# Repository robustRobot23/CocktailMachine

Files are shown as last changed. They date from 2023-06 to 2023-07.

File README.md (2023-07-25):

# CocktailMachine
Check the project Wiki for more information
Currently working on a cocktail machine to pour a shot of liquor, and pump in up to 4 mixers.
Machine contains:
  - 1 Stepper motor
  - 1 A4998 Stepper driver
  - 4 12V DC diagrpham pumps
  - 1 24 LED Neopixel ring
  - 1 Loadcell and HX711 breakout board
  - PCB V1
  - 1 OLED Screen
  - 2 rotary encoder dials and pushbuttons
  
**Code still not fully to working.** 
Currently creating the code structure:
  Machine class
  Cocktail class
  Pump Class

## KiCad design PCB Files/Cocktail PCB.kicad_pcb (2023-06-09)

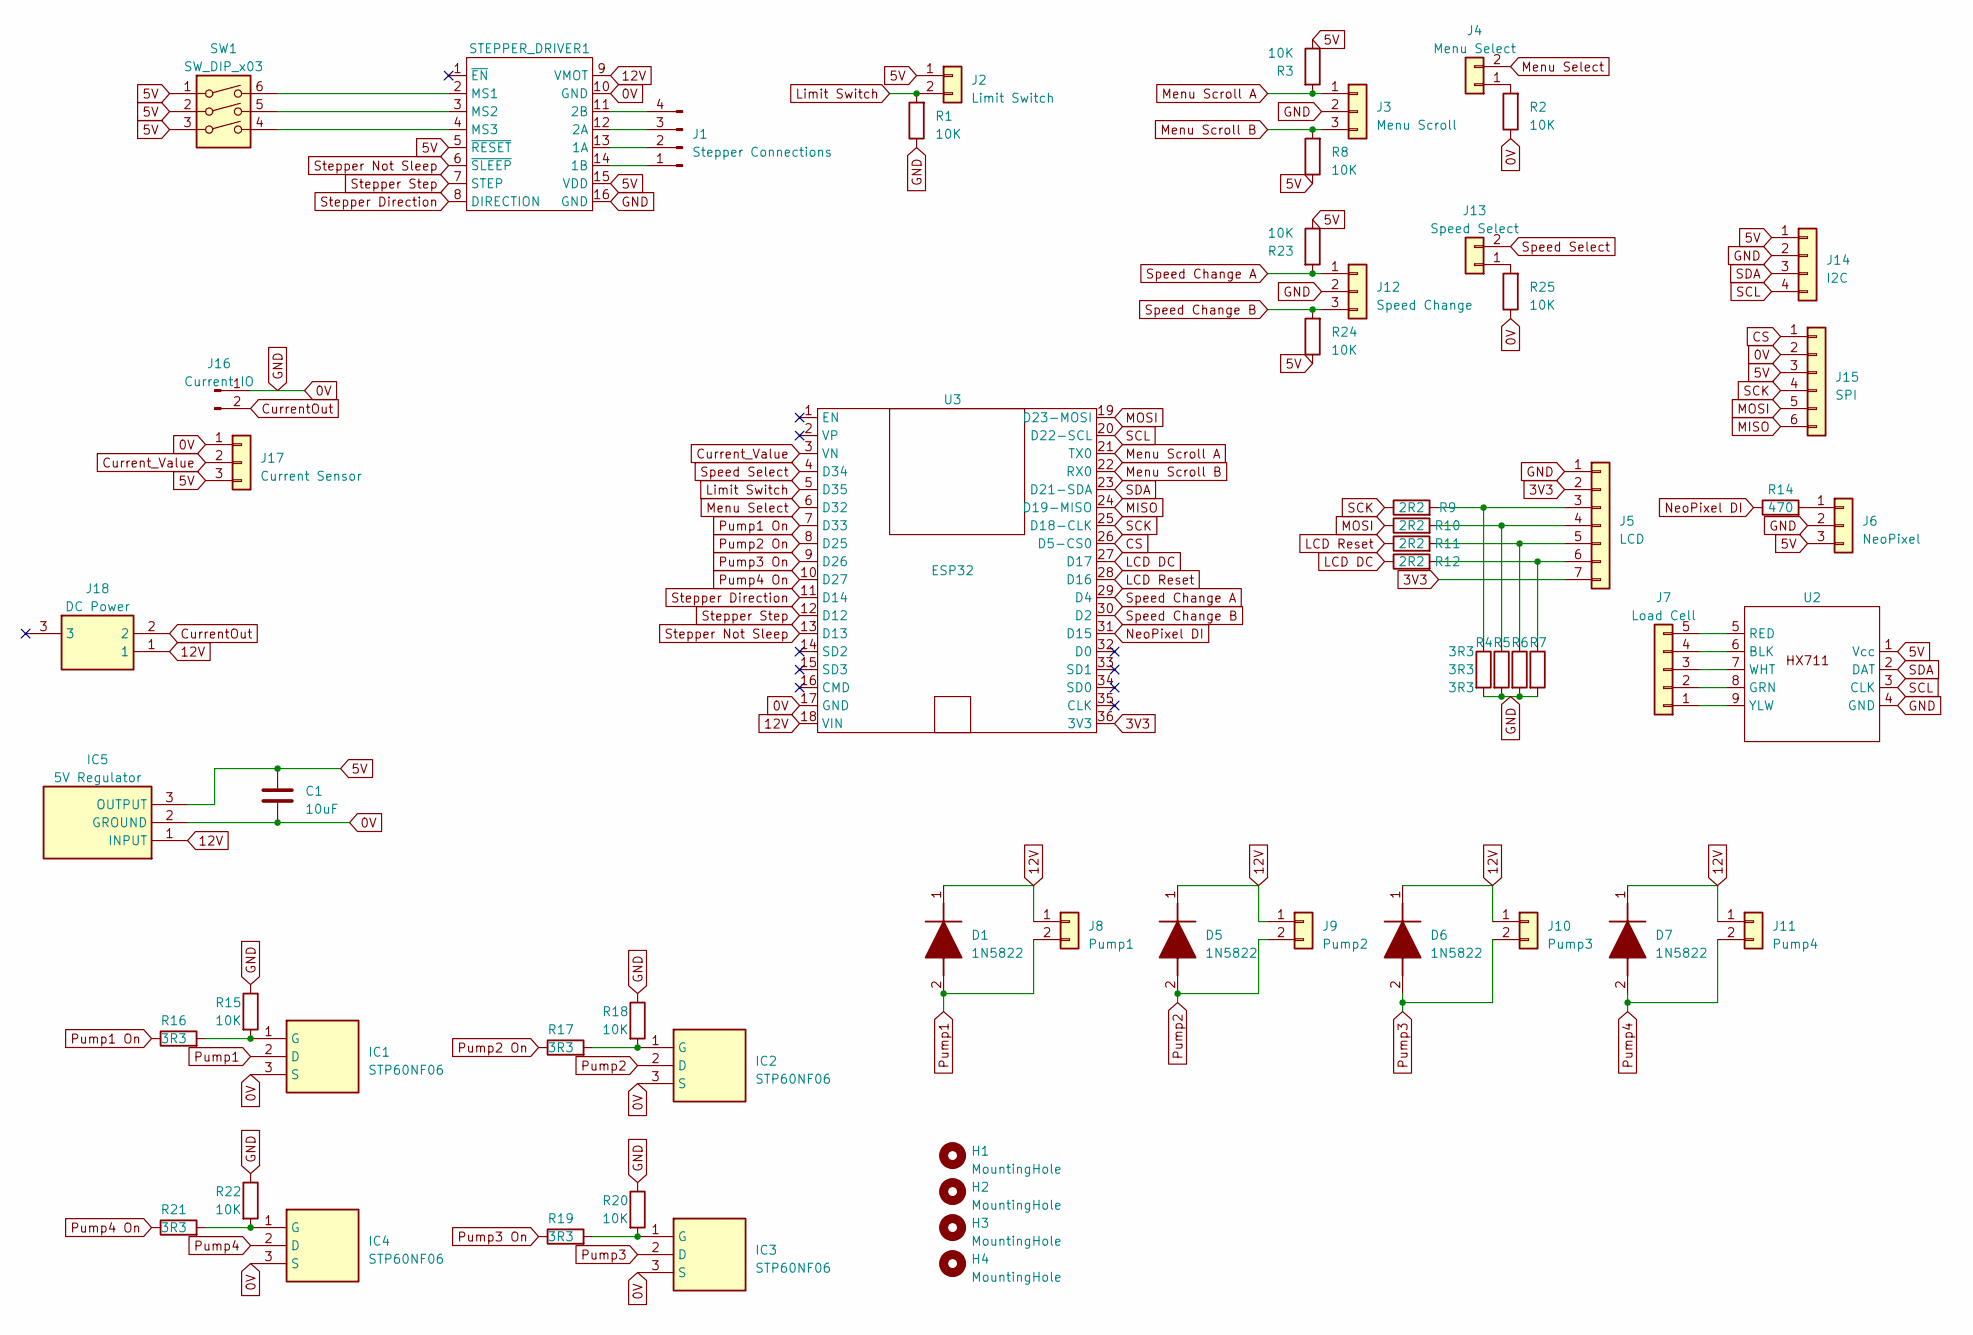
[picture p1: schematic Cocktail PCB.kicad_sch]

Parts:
C1: 10uF; CP_Radial_D5.0mm_P2.50mm
D1, D5, D6, D7: 1N5822; D_DO-41_SOD81_P10.16mm_Horizontal; Manufacturer_Part_Number 1N5822; Mouser Part Number 512-1N5822
H1, H2, H3, H4: MountingHole; MountingHole_3.5mm_Pad
IC1, IC2, IC3, IC4: STP60NF06; TO270P460X1020X2008-3P; Manufacturer_Part_Number STP60NF06; Mouser Part Number 511-STP60NF06
IC5: 5V Regulator; TO270P460X1020X2008-3P; Manufacturer_Part_Number LM340T-5.0; Mouser Part Number 926-LM340T-50
J1: Stepper Connections; PinHeader_1x04_P2.54mm_Vertical
J2: Limit Switch; PinHeader_1x02_P2.54mm_Vertical
J3: Menu Scroll; PinHeader_1x03_P2.54mm_Vertical
J4: Menu Select; PinHeader_1x02_P2.54mm_Vertical
J5: LCD; PinHeader_1x07_P2.54mm_Vertical
J6: NeoPixel; PinHeader_1x03_P2.54mm_Vertical
J7: Load Cell; PinHeader_1x05_P2.54mm_Vertical
J8: Pump1; PinHeader_1x02_P2.54mm_Vertical
J9: Pump2; PinHeader_1x02_P2.54mm_Vertical
J10: Pump3; PinHeader_1x02_P2.54mm_Vertical
J11: Pump4; PinHeader_1x02_P2.54mm_Vertical
J12: Speed Change; PinHeader_1x03_P2.54mm_Vertical
J13: Speed Select; PinHeader_1x02_P2.54mm_Vertical
J14: I2C; PinHeader_1x04_P2.54mm_Vertical
J15: SPI; PinHeader_1x06_P2.54mm_Vertical
J16: Current IO; PinHeader_1x02_P2.54mm_Vertical
J17: Current Sensor; PinHeader_1x03_P2.54mm_Vertical
J18: DC Power; DC Jack; Manufacturer_Part_Number PJ-102AH
R1, R2, R3, R8, R15, R18, R20, R22, R23, R24, R25: 10K; R_0805_2012Metric_Pad1.20x1.40mm_HandSolder
R4, R5, R6, R7, R16, R17, R19, R21: 3R3; R_0805_2012Metric_Pad1.20x1.40mm_HandSolder
R9, R10, R11, R12: 2R2; R_0805_2012Metric_Pad1.20x1.40mm_HandSolder
R14: 470; R_0805_2012Metric_Pad1.20x1.40mm_HandSolder
STEPPER_DRIVER1: A4988
SW1: SW_DIP_x03; DIL Switch
U2: HX711
U3: ESP32; DOIT ESP32 DEVKIT

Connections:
0V: C1.2, IC1.3 (S), IC2.3 (S), IC3.3 (S), IC4.3 (S), IC5.2 (GROUND), J3.2, J5.1, J6.2, J12.2, J14.2, J15.2, J16.1, J17.1, R1.1, R2.1, R4.2, R5.2, R6.2, R7.2, R15.1, R18.1, R20.1, R22.1, R25.1, STEPPER_DRIVER1.10 (GND), STEPPER_DRIVER1.16 (GND), U2.4 (GND), U3.17 (GND)
3V3: J5.2, J5.7, U3.36 (3V3)
5V: C1.1, IC5.3 (OUTPUT), J2.1, J6.3, J14.1, J15.3, J17.3, R3.1, R8.1, R23.1, R24.1, STEPPER_DRIVER1.5 (~RESET), STEPPER_DRIVER1.15 (VDD), SW1.1, SW1.2, SW1.3, U2.1 (Vcc)
12V: D1.1 (K), D5.1 (K), D6.1 (K), D7.1 (K), IC5.1 (INPUT), J8.1, J9.1, J10.1, J11.1, J18.1, STEPPER_DRIVER1.9 (VMOT), U3.18 (VIN)
CS: J15.1, U3.26 (D5-CS0)
CurrentOut: J16.2, J18.2
Current_Value: J17.2, U3.3 (VN)
LCD DC: R12.1, U3.27 (D17)
LCD Reset: R11.1, U3.28 (D16)
Limit Switch: J2.2, R1.2, U3.5 (D35)
MISO: J15.6, U3.24 (D19-MISO)
MOSI: J15.5, R10.1, U3.19 (D23-MOSI)
Menu Scroll A: J3.1, R3.2, U3.21 (TX0)
Menu Scroll B: J3.3, R8.2, U3.22 (RX0)
Menu Select: J4.2, U3.6 (D32)
NeoPixel DI: R14.1, U3.31 (D15)
unnamed: IC1.1 (G), R15.2, R16.2
unnamed: IC2.1 (G), R17.2, R18.2
unnamed: IC3.1 (G), R19.2, R20.2
unnamed: IC4.1 (G), R21.2, R22.2
unnamed: J1.1, STEPPER_DRIVER1.14 (1B)
unnamed: J1.2, STEPPER_DRIVER1.13 (1A)
unnamed: J1.3, STEPPER_DRIVER1.12 (2A)
unnamed: J1.4, STEPPER_DRIVER1.11 (2B)
unnamed: J4.1, R2.2
unnamed: J5.3, R4.1, R9.2
unnamed: J5.4, R5.1, R10.2
unnamed: J5.5, R6.1, R11.2
unnamed: J5.6, R7.1, R12.2
unnamed: J6.1, R14.2
unnamed: J7.1, U2.9 (YLW)
unnamed: J7.2, U2.8 (GRN)
unnamed: J7.3, U2.7 (WHT)
unnamed: J7.4, U2.6 (BLK)
unnamed: J7.5, U2.5 (RED)
unnamed: J13.1, R25.2
unnamed: STEPPER_DRIVER1.2 (MS1), SW1.6
unnamed: STEPPER_DRIVER1.3 (MS2), SW1.5
unnamed: STEPPER_DRIVER1.4 (MS3), SW1.4
Pump1: D1.2 (A), IC1.2 (D), J8.2
Pump1 On: R16.1, U3.7 (D33)
Pump2: D5.2 (A), IC2.2 (D), J9.2
Pump2 On: R17.1, U3.8 (D25)
Pump3: D6.2 (A), IC3.2 (D), J10.2
Pump3 On: R19.1, U3.9 (D26)
Pump4: D7.2 (A), IC4.2 (D), J11.2
Pump4 On: R21.1, U3.10 (D27)
SCK: J15.4, R9.1, U3.25 (D18-CLK)
SCL: J14.4, U2.3 (CLK), U3.20 (D22-SCL)
SDA: J14.3, U2.2 (DAT), U3.23 (D21-SDA)
Speed Change A: J12.1, R23.2, U3.29 (D4)
Speed Change B: J12.3, R24.2, U3.30 (D2)
Speed Select: J13.2, U3.4 (D34)
Stepper Direction: STEPPER_DRIVER1.8 (DIRECTION), U3.11 (D14)
Stepper Not Sleep: STEPPER_DRIVER1.6 (~SLEEP), U3.13 (D13)
Stepper Step: STEPPER_DRIVER1.7 (STEP), U3.12 (D12)

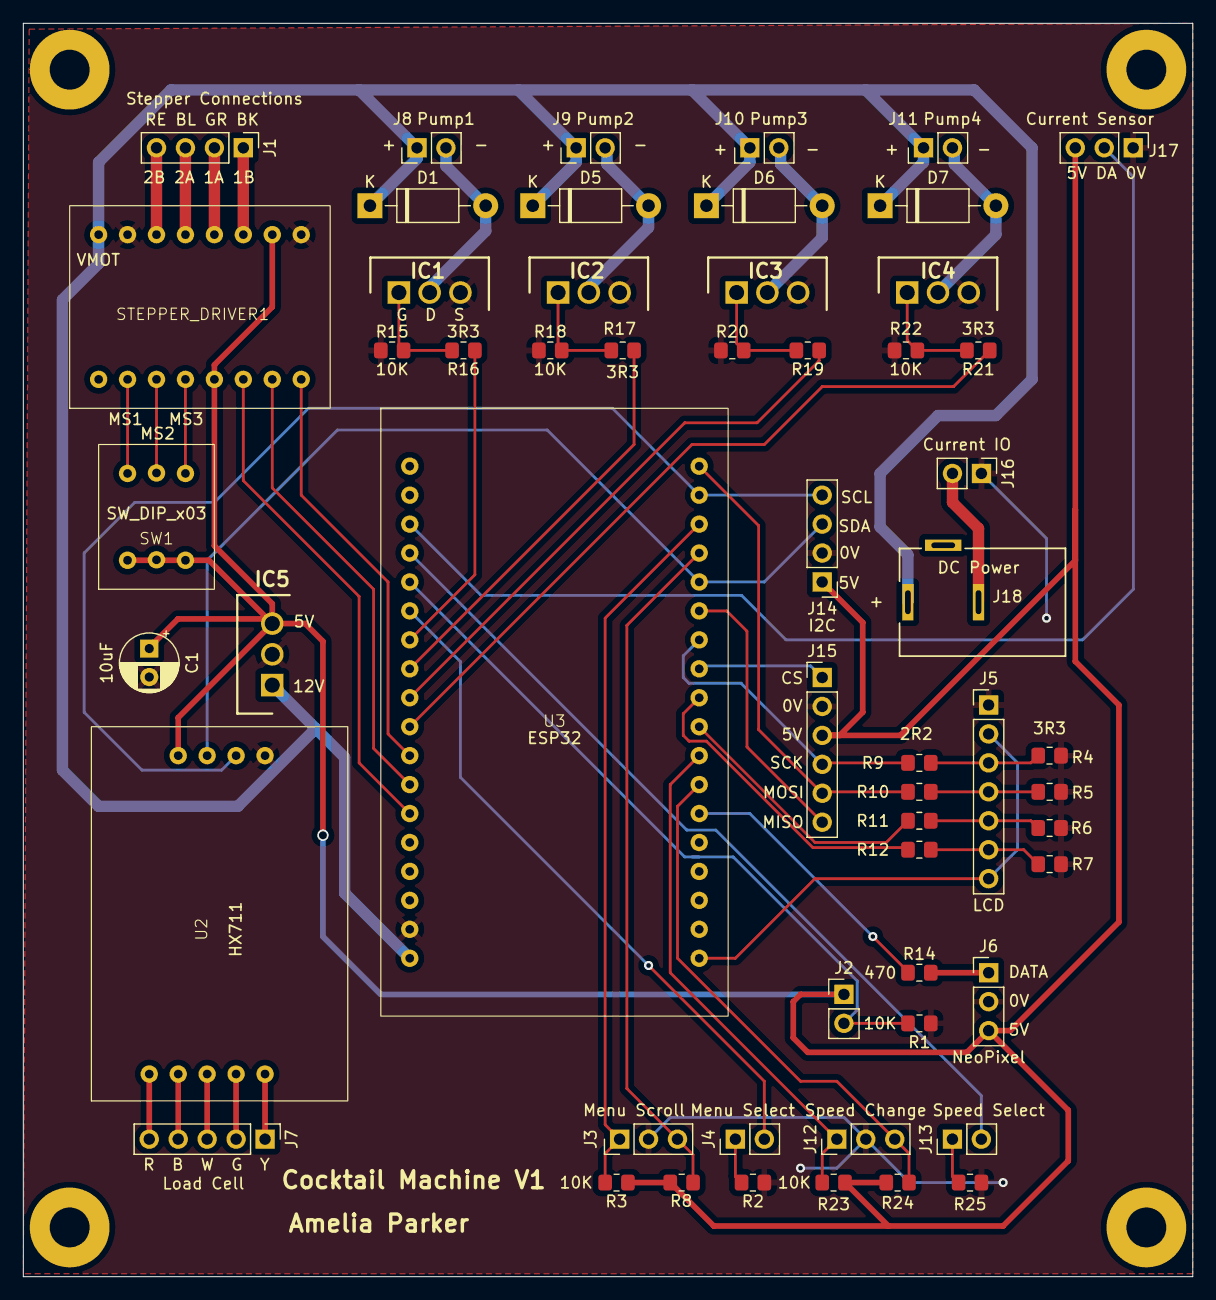
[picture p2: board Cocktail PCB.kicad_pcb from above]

Board: 2 copper layers, 102.6 x 110.0 mm, 60 parts (0 on the bottom side), 56 nets.

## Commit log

2023-06-09 First version of PCB. Contains a few errors, mainly not realising esp32 peripherals work on 3.3V logic
    [Cocktail PCB-B_Cu.gbl, Cocktail PCB-B_Mask.gbs, Cocktail PCB-B_Paste.gbp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]
2023-06-10 Added messy pump code
2023-06-10 Added pump class to turn pumps on and off. Each pump will need to be told the mL of the selected cocktail. The pumpRun method currently needs to be called frequently when pouring.
2023-06-10 Made a CocktailMachine class that holds info. This includes machine state, and progress of drink making. Pumps have own class. Cocktail is now seperate classs. Kernal can be absorbed into machine cla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
2023-06-12 Moved PCB files to new folder
    [Cocktail PCB-B_Cu.gbl, Cocktail PCB-B_Mask.gbs, Cocktail PCB-B_Paste.gbp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]
2023-06-12 Moved folders around
    [Cocktail PCB.kicad_pcb, Cocktail PCB.kicad_sch]
2023-06-12 Updating folders
    [Cocktail PCB.kicad_pcb, Cocktail PCB.kicad_sch]
2023-06-19 Moved pump1 etc objects to static memory
2023-06-19 Moved pump1 etc objects inside pumpsInit()
2023-06-19 Initialising ingredients works mostly. ESP32 restarting when entering displayMenu state. Likely an empty availableCocktails array
